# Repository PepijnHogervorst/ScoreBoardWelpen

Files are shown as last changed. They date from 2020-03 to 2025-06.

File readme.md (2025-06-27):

# Interactive score board

A RGB scoreboard for 6 teams to keep track of the team score during `Welpenkamp`.
A intelegent scoreboard that keeps track of score, person that should press the button and controls led strips using an arduino with ethernet communication. The communication between PC and arduino is MQTT. Using simple topics

## How to use

* Laptop is required with ethernet connection (wifi won't work)
* Ethernet cable between laptop and controller

Ethernet settings:  

* IP Laptop / PC = `192.168.178.99`
* IP Arduino = `192.168.178.98`

## MQTT API

MQTT settings:

* No username / password
* Port 1883

### Scoreboard program

Topic: `Scoreboard/ButtonProgram`

Payload:

```json
{
    "Group":1,
    "Points":55
}
```

The arduino will respond with a ready signal if the button is pressed:

Topic: `Scoreboard/Ready`

Payload: No payload required

### Party mode

Topic: `Scoreboard/Party`

Payload:

```json
{
    "Program":0,
    "Delay":1
}
```

Where program is a number with enum values:

``` csharp
public enum PartyProgram
{
    FullRainbow = 0,
    RandomRain,
    ColorWipe,
    CollorCyclePillar,
}
```

### Strobe

Topic: `Scoreboard/Strobe`

Payload:

```json
{
    "Program":0,
    "Delay":1
}
```

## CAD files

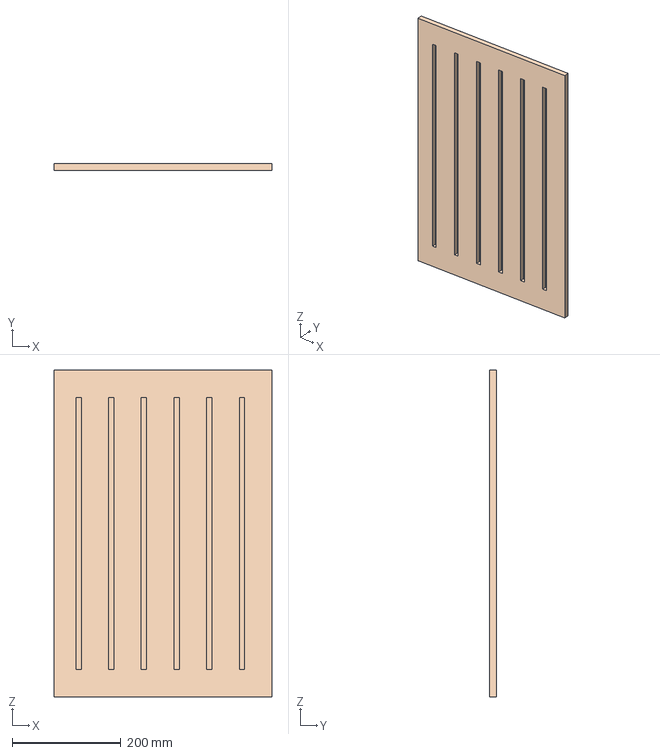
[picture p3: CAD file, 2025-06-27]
3D ontwerp/PuntenbordWelpen.FCStd
400.0 x 12.0 x 600.0 mm

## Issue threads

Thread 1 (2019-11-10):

Communication between raspberry pi and arduino

PepijnHogervorst, 2019-11-10:
Setup protocol and test functions to set at least 6 different ledstrips to at least 100 length of led strips

PepijnHogervorst, 2021-05-28:
Fixed #1 using MQTT. MQTTnet broker and M2MQTT client. Looking back only MQTTnet library was needed but that is knownledge i didn't posses at that time.

Closed 2021-05-28.

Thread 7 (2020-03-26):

[UWP] Layout

PepijnHogervorst, 2020-03-26:
Updates on layout from raspberry pi

PepijnHogervorst, 2021-05-28:
WPF is easier and not needed to go to UWP for this application. So this issue is rejected

Closed 2021-05-28.

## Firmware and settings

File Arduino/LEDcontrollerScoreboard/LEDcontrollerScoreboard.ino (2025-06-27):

/************************************************************************/
/*                               INCLUDES                               */
/************************************************************************/
#include <ArduinoJson.h>
#include <Adafruit_NeoPixel.h>
#include <EEPROM.h>
#include <Ethernet.h>
#include <PubSubClient.h>
#include <SPI.h>
/************************************************************************/
/*                                                                      */
/************************************************************************/
// Protocol works as following:
// Arduino receives commands from rpi of size: 6 bytes. In following structure:
// gXpXXX -> the first X is for the group 
// groupNr points
// Brightness is also adjustable using:
// bbbXXX => XXX is brightness from 0 to 255
// Party mode is actived using:
// pppXXX => XXX is party mode program selection
// Stop party mode:
// sXXXXX => dont care as long if msg is 6 bytes
/************************************************************************/
/*                             DEFINITIONS                              */
/************************************************************************/
// If DEBUG is defined (uncommented)the arduino will do a RGB loop through every LED_GROUP
//#define DEBUG
// Uncomment this to test voltage drop on led strip, only works if debug is defined
//#define DEBUG_VOLTAGE_DROP

// PIN definitions of led strip groups
#define LED_GROUP_1             2
#define LED_GROUP_2             3
#define LED_GROUP_3             4
#define LED_GROUP_4             5
#define LED_GROUP_5             6
#define LED_GROUP_6             7

// INPUTS
#define BTN_ARCADE              40
// OUTPUTS
#define BTN_INDICATOR           41

// The total number of led strip groups:
#define NUM_OF_GROUPS           6
// Number of leds per group (all groups have the same amount of LEDS)
#define NUM_OF_PIXELS           98

// Max brightness of the leds 
#define BRIGHTNESS              200
#define BRIGHTNESS_ADDRESS      0

#define LED_OFFSET_1            0
#define LED_OFFSET_2            (255 * 1)/ NUM_OF_GROUPS 
#define LED_OFFSET_3            (255 * 2)/ NUM_OF_GROUPS 
#define LED_OFFSET_4            (255 * 3)/ NUM_OF_GROUPS 
#define LED_OFFSET_5            (255 * 4)/ NUM_OF_GROUPS 
#define LED_OFFSET_6            (255 * 5)/ NUM_OF_GROUPS 


/************************************************************************/
/*                                                                      */
/************************************************************************/

/************************************************************************/
/*                            GLOBAL VARIABLES                          */
/************************************************************************/
// One neopixel object is used, and the pin is switched when a different strip is needed to put on.
Adafruit_NeoPixel led_strip;

String inputString = "";
String ledMsg = "";
bool messageReceived = false;
bool IsPartyMode = false;
bool IsArcadeBtnEnabled = false;
bool PartyProgramChanged = true;
bool reconnectTimerFlag = true;
uint8_t PartyProgram = 0;
uint8_t LED_Brightness = 0;
uint16_t PartyDelayTime = 5;
uint16_t strobe_delay = 500;
uint32_t strobe_color = led_strip.Color(255,255,255);
uint8_t strobe_brightness = 100;
bool is_strobe_active = false;

int GroupNr = 0;
int Points = 0;

const char SoftwareVersion[] = "V0.1";
const char compile_date[] = __DATE__ " " __TIME__;
const uint32_t MY_COLORS[] = {
  led_strip.Color(0, 255, 0),
  led_strip.Color(255, 0, 0),
  led_strip.Color(0, 0, 255),
  led_strip.Color(255, 255, 0),
  led_strip.Color(0, 255, 255),
  led_strip.Color(255, 0, 255),
  led_strip.Color(255,255,255)
};

// Lookup table 
byte neopix_gamma[] = {
    0,  0,  0,  0,  0,  0,  0,  0,  0,  0,  0,  0,  0,  0,  0,  0,
    0,  0,  0,  0,  0,  0,  0,  0,  0,  0,  0,  0,  1,  1,  1,  1,
    1,  1,  1,  1,  1,  1,  1,  1,  1,  2,  2,  2,  2,  2,  2,  2,
    2,  3,  3,  3,  3,  3,  3,  3,  4,  4,  4,  4,  4,  5,  5,  5,
    5,  6,  6,  6,  6,  7,  7,  7,  7,  8,  8,  8,  9,  9,  9, 10,
   10, 10, 11, 11, 11, 12, 12, 13, 13, 13, 14, 14, 15, 15, 16, 16,
   17, 17, 18, 18, 19, 19, 20, 20, 21, 21, 22, 22, 23, 24, 24, 25,
   25, 26, 27, 27, 28, 29, 29, 30, 31, 32, 32, 33, 34, 35, 35, 36,
   37, 38, 39, 39, 40, 41, 42, 43, 44, 45, 46, 47, 48, 49, 50, 50,
   51, 52, 54, 55, 56, 57, 58, 59, 60, 61, 62, 63, 64, 66, 67, 68,
   69, 70, 72, 73, 74, 75, 77, 78, 79, 81, 82, 83, 85, 86, 87, 89,
   90, 92, 93, 95, 96, 98, 99,101,102,104,105,107,109,110,112,114,
  115,117,119,120,122,124,126,127,129,131,133,135,137,138,140,142,
  144,146,148,150,152,154,156,158,160,162,164,167,169,171,173,175,
  177,180,182,184,186,189,191,193,196,198,200,203,205,208,210,213,
  215,218,220,223,225,228,231,233,236,239,241,244,247,249,252,255 };

// memory pools for JSON parsing
StaticJsonDocument<256> doc_receive;
StaticJsonDocument<256> doc_send;

// Ethernet config arduino!
byte mac[] = { 0xD1, 0xAD, 0xBE, 0xEF, 0xCE, 0xAA };
// IPAddress ip(192, 168, 68, 90);
// IPAddress server(192, 168, 68, 102);
IPAddress ip(192, 168, 178, 98);
IPAddress server(192, 168, 178, 99);

EthernetClient ethClient;
PubSubClient mqtt_client(ethClient);

// MQTT config
const char topic_button_prog[]  = "Scoreboard/ButtonProgram";
const char topic_party[]        = "Scoreboard/Party";
const char topic_brightness[]   = "Scoreboard/Brightness";
const char topic_stop_party[]   = "Scoreboard/Clear";
const char topic_strobe[]       = "Scoreboard/Strobe";

const char topic_status[]       = "Scoreboard/Status";
const char topic_ready[]        = "Scoreboard/Ready";

// General variables
unsigned long prev_keep_alive;
/************************************************************************/
/*                                                                      */
/************************************************************************/


/************************************************************************/
/*                               STRUCTS                                */
/************************************************************************/
struct RainDrop_t
{
  int8_t State;
  uint8_t LedPin;
  uint8_t Location;
};
/************************************************************************/
/*                                                                      */
/************************************************************************/


/************************************************************************/
/*                             PROTOTYPES                               */
/************************************************************************/
// MQTT prototypes
void callback(char* topic, byte* payload, unsigned int length);
void reconnect();
void keep_alive();
void decipher_mqtt_message(char* topic, char payload[]);
void mqtt_set_party();
void mqtt_set_buttonprogram();
void mqtt_set_brightness();
void mqtt_stop_party();

void WriteLedStrip();
int groupNrToPin(int nr);
int groupNrToOffset(int nr);
uint32_t Wheel(byte WheelPos);
void DebugLoop(void);
void ClearLEDstrips(void);

// Party prototypes
void PartyLoop(void);
void PP_Full_rainbow(void);
void PP_Random_Rain(void);
void PP_ColorWipes(void);
// Button control prototypes
void CheckButtonControl(void);

void ColorWipe(uint32_t color, int delayTime);
/************************************************************************/
/*                                                                      */
/************************************************************************/


/************************************************************************/
/*                                 SETUP                                */
/************************************************************************/
void setup() {
  // Init serial communication:
  Serial.begin(115200);

  Serial.print("LEDcontrollerScoreboard ");
  Serial.println(SoftwareVersion);
  Serial.print("Compile date: ");
  Serial.println(compile_date);
  // Allocate memory for string
  inputString.reserve(200);
  
  // Startup delay to let power supply stabilize
  delay(3000);

  // Retrieve brightness from eeprom
  LED_Brightness = EEPROM.read(BRIGHTNESS_ADDRESS);
  Serial.print("Brightness set to: ");
  Serial.println(LED_Brightness);
  if (LED_Brightness == 0)
  {
    LED_Brightness = BRIGHTNESS;
  }

  // Initialize MQTT config
  mqtt_client.setServer(server, 1883);
  mqtt_client.setCallback(callback);

  // Start ethernet on static IP
  Ethernet.begin(mac, ip);
  Serial.print("Arduino ip=");
  Serial.println(ip);


  // Init the led strip
  led_strip = Adafruit_NeoPixel(NUM_OF_PIXELS, LED_GROUP_1, NEO_RGB  + NEO_KHZ800);
  led_strip.setBrightness(LED_Brightness);
  led_strip.begin();
  led_strip.clear();

  ClearLEDstrips();

  // Init IO
  pinMode(BTN_ARCADE, INPUT);
  pinMode(BTN_INDICATOR, OUTPUT);
  digitalWrite(BTN_INDICATOR, LOW);

  // Extra randomness for start color 
  randomSeed(analogRead(0));

  Serial.println("Initialization done!");
  #ifdef DEBUG 
  #ifdef DEBUG_VOLTAGE_DROP
  Serial.println("Debug VOLTAGE DROP mode active");
  #else
  Serial.println("Debug mode active");
  #endif
  #endif
}
/************************************************************************/
/*                                                                      */
/************************************************************************/

/************************************************************************/
/*                                MAIN LOOP                             */
/************************************************************************/
void loop() {
  #ifndef DEBUG
  // Handle MQTT connection and keep alive
  if (!mqtt_client.connected())
  {
    reconnect();
  }
  mqtt_client.loop();

  keep_alive();
  
  // Check what mode the arduino is in
  if (IsPartyMode)
  {
    PartyLoop();
  }
  if (IsArcadeBtnEnabled)
  {
    if (digitalRead(BTN_ARCADE) == HIGH)
    {
      delay(70);
      if (digitalRead(BTN_ARCADE) == HIGH)
      {
        WriteLedStrip();
      }
    }
  }
  else
  {
    CheckButtonControl();
  }
  
  #else
  // Debug mode! 
  PartyLoop();
  // DebugLoop();
  #endif
}
/************************************************************************/
/*                                                                      */
/************************************************************************/

/************************************************************************/
/*                              EVENTS                                  */
/************************************************************************/
// MQTT callback when message on subscribed topic is received
void callback(char* topic, byte* payload, unsigned int length) 
{
  // Cast payload to string
  char content[length] = "";
  char character;
  for (int num = 0; num < length; num++) 
  {
    //character = payload[num];
    content[num] = payload[num];
  }

  Serial.println();
  Serial.println("Received msg!");
  Serial.print("Topic: ");
  Serial.println(topic);
  Serial.print("Payload: ");
  Serial.println(content);

  // Parse payload
  decipher_mqtt_message(topic, content);
}
/************************************************************************/
/*                                                                      */
/************************************************************************/

/************************************************************************/
/*                              FUNCTIONS                               */
/************************************************************************/
#pragma region MQTT methods
void reconnect() 
{
  // Loop until we're reconnected
  if (!mqtt_client.connected()) 
  {
    // Only try to reconnect once every 4 seconds
    if (!reconnectTimerFlag) return;
    
    reconnectTimerFlag = false;
    // Attempt to connect
    if (mqtt_client.connect("arduinoClient")) 
    {
      Serial.println("Connected to MQTT broker!");
      
      // Once connected, resubscribe to topics:
      mqtt_client.subscribe(topic_button_prog);
      mqtt_client.subscribe(topic_party);
      mqtt_client.subscribe(topic_brightness);
      mqtt_client.subscribe(topic_stop_party);
      mqtt_client.subscribe(topic_strobe);
      
      // Publish status / keep alive in JSON format
      char send_buf[100];

      doc_send.clear();
      doc_send["State"] = "Alive";
      doc_send["Brightness"] = LED_Brightness;
      doc_send["Version"] = SoftwareVersion;

      serializeJson(doc_send, send_buf);
      mqtt_client.publish(topic_status, send_buf);
    } 
    else 
    {
      Serial.print("failed to connect to mqtt broker, rc=");
      Serial.print(mqtt_client.state());
      Serial.print(" ip server=");
      Serial.println(server);
    }
  }
}

void keep_alive()
{
  static uint8_t reconnectCounter = 0;
  unsigned long current_time = millis();

  // Check time elapsed is more than 1 sec
  if ((current_time - prev_keep_alive) >= 1000)
  {
    char send_buf[100];
    doc_send.clear();
    doc_send["State"] = "Alive";
    doc_send["Brightness"] = LED_Brightness;
    doc_send["Version"] = SoftwareVersion;

    // Publish alive message
    if (mqtt_client.connected())
    {
      serializeJson(doc_send, send_buf);
      mqtt_client.publish(topic_status, send_buf);
    }

    // Update prev time
    prev_keep_alive = current_time;

    if (reconnectCounter >= 3)
    {
      reconnectCounter = 0;
      reconnectTimerFlag = true;
    }
    else
    {
      reconnectCounter++;
    }
  }
}

void decipher_mqtt_message(char* topic, char payload[])
{
  // Deserialize json
  DeserializationError exception = deserializeJson(doc_receive, payload);
  
  // Check for succes of deserialization
  if (exception)
  {
    Serial.println("Failed to deserialize JSON..");
    return;
  }

  // Compare topic!
  if (strcmp(topic, topic_party) == 0)
  {
    mqtt_set_party();
  }
  else if (strcmp(topic, topic_button_prog) == 0)
  {
    mqtt_set_buttonprogram();
  }
  else if (strcmp(topic, topic_brightness) == 0)
  {
    mqtt_set_brightness();
  }
  else if (strcmp(topic, topic_stop_party) == 0)
  {
    mqtt_stop_party();
  }
  else if (strcmp(topic, topic_strobe) == 0)
  {
    mqtt_set_strobe();
  }
}

void mqtt_set_party()
{
  // Set Party mode!
  IsPartyMode = true;

  // Clear score if set
  IsArcadeBtnEnabled = false;
  digitalWrite(BTN_INDICATOR, LOW);

  // Get the program nr and delay time
  uint8_t program = doc_receive["Program"];
  uint8_t delay = doc_receive["Delay"];

  // Set delay limits
  if (delay > 99)
  {
    delay = 99;
  }
  else if (delay == 0)
  {
    delay = 5;
  }
  
  // Set program 
  if (program >= 0 && program < 9)
  {
    if (program != PartyProgram || 
        delay != PartyDelayTime)
    {
      ClearLEDstrips();
      PartyProgram = program;
      PartyDelayTime = delay;
      PartyProgramChanged = true;

      Serial.print("Next level party: ");
      Serial.println(program);
      Serial.print("BPM:");
      Serial.println(delay);
    }
  }
}

void mqtt_set_buttonprogram()
{
  if (IsPartyMode)
  {
    Serial.println("Party canceled..");
    ClearLEDstrips();
  }
  IsPartyMode = false;
  IsArcadeBtnEnabled = true;

  // Set LED in arcade button to signal it is active
  digitalWrite(BTN_INDICATOR, HIGH);

  GroupNr = doc_receive["Group"];
  Points = doc_receive["Points"];

  // Check limits of points
  if (Points > led_strip.numPixels())
  {
    Points = led_strip.numPixels();
  }
  else if (Points < 0)
  {
    Points = 0;
  }
}

void mqtt_set_brightness()
{
  uint8_t bright = doc_receive["Brightness"];

  // Update ledstrip brightness
  led_strip.setBrightness(bright);
  LED_Brightness = bright;

  // Save brightness in eeprom
  EEPROM.write(BRIGHTNESS_ADDRESS, bright);

  // Log to console
  Serial.println();
  Serial.print("Brightness set to: ");
  Serial.println(bright);
  Serial.println();
}

void mqtt_stop_party()
{
  Serial.println("Party is over BOYS.. Clearing ledstrips");
  IsPartyMode = false;
  ClearLEDstrips();
}

void mqtt_set_strobe()
{
  strobe_brightness = doc_receive["Brightness"];
  strobe_color = doc_receive["Color"];
  strobe_delay = doc_receive["Time"];
  is_strobe_active = doc_receive["Active"];

  if (is_strobe_active)
  {
    Serial.println("Strobe ACTIVE!");
  }
  else
  {
    Serial.println("Strobe OFFLINE!");
  }
  
  
}
#pragma endregion

void EnableArcadeButton()
{
  IsArcadeBtnEnabled = true;
  // Copy message to ledMsg
  ledMsg = inputString;
  // Set LED in arcade button to signal it is active
  digitalWrite(BTN_INDICATOR, HIGH);

  // Calculate group and points
  char grpChar = ledMsg.charAt(1);
  String pointsString = inputString.substring(3);

   // Get the group nr and pin nr
  GroupNr = grpChar - '0';

  for(int i = 0; i < pointsString.length(); i++)
  {
    if(!isDigit(pointsString.charAt(i)))
    {
      // points string not digit, return
      Serial.println("POINTS NOT ALL DIGITS, NOT SETTING LEDS");
      return;
    }
  }

  // Set points
  Points = pointsString.toInt();
  if (Points > led_strip.numPixels())
  {
    Points = led_strip.numPixels();
  }
  else if (Points < 0)
  {
    Points = 0;
  }
}

void WriteLedStrip()
{
  int ledPin = 0; 

  delay(100);
  IsArcadeBtnEnabled = false;
  digitalWrite(BTN_INDICATOR, LOW);

  ledPin = groupNrToPin(GroupNr);
  // Check if pin is valid otherwise return
  if(ledPin == 0)
    return;
  
  Serial.print("Group: ");
  Serial.print(GroupNr);
  Serial.print("   Points: ");
  Serial.println(Points);
  
  // Set ledstrip pin to group ledstrip pin
  led_strip.setPin(ledPin);

  // Get random offset 
  long randomNr = random(256);
  uint16_t loopCount = 1;
  uint16_t delayTime = (5000 / Points) - 1;
  
  // Clear previously show points on strip
  led_strip.clear();
  led_strip.show();
  do
  {
    for(int16_t i = 0; i < loopCount; i++)
    {
      led_strip.setPixelColor(i, Wheel(((i * 256 / led_strip.numPixels()) + randomNr) & 255));
    }
    led_strip.show();
    delay(delayTime);
    loopCount++;
  }
  while(loopCount <= Points);

  Serial.println("LEDS set! Waiting for new command..");

  // Create ready msg in JSON format
  char send_buf[100];
  doc_send.clear();
  doc_send["Ready"] = true;
  
  // Publish ready message
  if (mqtt_client.connected())
  {
    serializeJson(doc_send, send_buf);
    mqtt_client.publish(topic_ready, send_buf);
  }
}

int groupNrToPin(int nr)
{
  int pin = 0;
  switch(nr)
  {
    case 1: pin = LED_GROUP_1; break;
    case 2: pin = LED_GROUP_2; break;
    case 3: pin = LED_GROUP_3; break;
    case 4: pin = LED_GROUP_4; break;
    case 5: pin = LED_GROUP_5; break;
    case 6: pin = LED_GROUP_6; break;
  }

  return pin;
}

// Input a value 0 to 255 to get a color value.
// The colours are a transition r - g - b - back to r.
uint32_t Wheel(byte WheelPos) 
{
  WheelPos = 255 - WheelPos;
  if(WheelPos < 85) {
    return led_strip.Color(255 - WheelPos * 3, 0, WheelPos * 3,0);
  }
  if(WheelPos < 170) {
    WheelPos -= 85;
    return led_strip.Color(0, WheelPos * 3, 255 - WheelPos * 3,0);
  }
  WheelPos -= 170;
  return led_strip.Color(WheelPos * 3, 255 - WheelPos * 3, 0,0);
}

void DebugLoop(void)
{
  static uint8_t groupCounter = 1;
  int ledPin = 0;
  if (groupCounter > NUM_OF_GROUPS)
  {
    groupCounter = 1;
  }
  // Set pin to right group:
  ledPin = groupNrToPin(groupCounter);
  led_strip.clear();
  led_strip.setPin(ledPin);

  // Randomness
  long randomNr = random(256);

  // Show LEDS 
  for(int16_t i = 0; i < led_strip.numPixels(); i++)
  {
    #ifdef DEBUG_VOLTAGE_DROP
    led_strip.setPixelColor(i, led_strip.Color(255,255,255));
    #else
    led_strip.setPixelColor(i, Wheel(((i * 256 / led_strip.numPixels()) + randomNr) & 255));
    #endif
  }
  led_strip.show();
  Serial.print("LEDs group ");
  Serial.print(groupCounter);
  Serial.println(" set!");
  delay(250);

  groupCounter++;
}

int groupNrToOffset(int nr)
{
  int pin = 0;
  switch(nr)
  {
    case 1: pin = LED_OFFSET_1; break;
    case 2: pin = LED_OFFSET_2; break;
    case 3: pin = LED_OFFSET_3; break;
    case 4: pin = LED_OFFSET_4; break;
    case 5: pin = LED_OFFSET_5; break;
    case 6: pin = LED_OFFSET_6; break;
  }

  return pin;
}

void ClearLEDstrips()
{
  int pin = 0;
  for (int i = 1; i <= NUM_OF_GROUPS; i++)
  {
    pin = groupNrToPin(i);
    led_strip.setPin(pin);
    led_strip.clear();
    led_strip.show();
  }
}

#pragma region PARTY PROGRAM FUNCTIONS
void PartyLoop(void)
{
  static bool was_strobe_active = true;
  if (is_strobe_active)
  {
    was_strobe_active = true;
    PP_Strobe();
    return;
  }

  if (was_strobe_active)
  {
    led_strip.setBrightness(LED_Brightness);
    was_strobe_active = false;
  }
  

  switch (PartyProgram)
  {
    case 0:
      if (PartyProgramChanged)
      {
        PartyProgramChanged = false;
        Serial.println("Full Rainbow Party!!");
      }
      PP_Full_Rainbow();
      break;
  
    case 1:
      if (PartyProgramChanged)
      {
        PartyProgramChanged = false;
        Serial.println("Random Rain Party!!");
      }
      PP_Random_Rain();
      break;

    case 2:
      if (PartyProgramChanged)
      {
        PartyProgramChanged = false;
        Serial.println("Color Wipes Party!!");
      }
      PP_ColorWipes();
      break;

    case 3:
      if (PartyProgramChanged)
      {
        PartyProgramChanged = false;
        Serial.println("WOW single color rainbow!!");
      }
      PP_Rainbow_Single_Color();
      break;
    
    case 4:
      if (PartyProgramChanged)
      {
        PartyProgramChanged = false;
        Serial.println("Undefined program for now..");
      }
      
      break;

    default:
      break;
  }
  
}
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

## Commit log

2019-11-10 #2 Created GPIO script
    Linked event to button press, NEED TO TEST THIS
2019-11-16 #2 copied GPIO script to device
2019-12-02 #0 Layout Scoreboard page edited
    Added gradient background and arcade button event hook
2019-12-16 #0 Layout device page added
2019-12-19 #5 created arduino script
2019-12-19 #5 Written arduino code, need to test led strips
2020-03-21 #5 Arduino added debug mode
2020-03-22 #5 Arduino party mode
    NOT FINISHED, to do: party mode led wheel offset per strip using defines
2020-03-24 #5 Arduino party mode edited
2020-03-24 #5 Big improvements arduino code
    Added serial timeout that clears input buffer
    Added adjustable brightness (saved and loaded in EEPROM)
    Added decifer function to set birhgtness / party mode / normal mode
2020-03-27 #5 ARduino updated to control button
2020-03-29 #1 Added listen function when writing to arduino
2020-07-07 #0 Arduino update
2020-07-09 #0 Added Party speed and program ColorWipes
    In WPF and arduino code
2020-07-11 #0 Added button control to start party
    And toggle party.
    Hold down button for 3 to 5 seconds to start / stop party mode. Click (shorter than 1 sec) to change program
    [LEDcontrollerScoreboard.ino]
2020-10-23 #0 Add ready mqtt message when leds set
2020-10-23 #0 Trying to get ethernet working
    Maybe look at this https://forum.arduino.cc/index.php?topic=475101.0 for solution direct
2021-05-28 #0 3D cad model to repo
    [PuntenbordWelpen.FCStd]
2021-05-28 #0 Update arduino IP broker
    [LEDcontrollerScoreboard.ino]
